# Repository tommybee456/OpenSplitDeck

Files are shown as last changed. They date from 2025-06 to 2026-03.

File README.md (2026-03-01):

# OpenSplitDeck (v0.3)

A custom modular wireless controller inspired by the Steam Deck and Steam Controller. Features trackpads, detachable halves, and full HID support. Built from scratch using nRF52840 microcontrollers and the Enhanced ShockBurst protocol. [Video](https://youtu.be/ycMgIToLav8?si=cVztny4IiIS_V4oI) 

Join the [Discord!](https://discord.gg/ZtV34Hwx7y)

> **Note**  
> This project is in an early development stage — v0.3. Expect breaking changes, bugs, and frequent updates.

---

## 🚀 Project Goals

- 🎮 Emulate a Steam Deck-like controller with modular, wireless halves
- 🖱️ Support mouse, keyboard, and gamepad HID modes
- 🧲 Custom-built trackpads using the Azoteq IQS7211E sensor
- 🔋 Magnetic pogo-pin charging and attachment system
- 🛠️ Fully open-source hardware and firmware

---

## 😎 Current Status

- 🎮 Emulates a DS4 Controller - This lets us use steam input for the trackpads. Ideally I want it to show up as a steamdeck controller but that is seeming like a much harder task than I thought.
- 🖱️ Support mouse, keyboard, and gamepad HID modes. - Kinda. Mouse and keyboard are properly setup in the HID desccriptors, I just have not implpemented them yet.
- 🧲 Custom-built trackpads using the Azoteq IQS7211E sensor - Yes.
- 🔋 Magnetic pogo-pin charging and attachment system. - Yes but they only support charging. I would like to find a way to make the 2 halves of the controller communicate with each other.
- 🛠️ Fully open-source hardware and firmware - 😎

Controller is still definetly in the early phases. However it does function and work as expected. There is still a lot to improve, optimize and other features to add. Stay tuned for the progression of this project and feel free to build one yourself! Let me know if my instructions are bad.

---

## ✅ v0.3 Development Checklist

### Hardware
- [x] Left and right controller halves (nRF52840)
- [x] USB dongle (nRF52840)
- [x] Custom trackpad PCBs (IQS7211E)
- [ ] 3D printable version of the Shell
- [x] Controller PCBs(left + right)
- [ ] Joystick PCBs(to drive down cost)
- [ ] gp2040ce + nrf dongle

### Firmware
- [x] ESB-based wireless communication
- [x] Mouse + Gamepad + Keyboard HID reports
- [x] Input parsing for trackpads and buttons
- [x] Haptics
- [X] Rumble support (Could still be improved)
- [x] Gyro Support
- [x] Calibration routines + save to internal memory
- [ ] Configurable modes (gesture/tap/mouse/gamepad)
- [x] Steam Input compatibility or XInput compatibility(This is now done through DS4)
- [ ] Capacitive Joystick

### 3d Modeling
- [ ] 3d Printable Case(Started, its in the STEP file)
- [ ] 3d Printable Shoulder Button Structure(Experimental Version in STEP file)
- [ ] 3d Printable Trigger Insert
- [ ] Trigger Locks

### Other
- [ ] Improve documentation and diagrams
- [x] Add Screens
- [ ] Design a UI or config utility(either software or adding screens)
- [X] Firmware migration to Zephyr
- [X] Optimize latency and packet loss handling (could still be better)
- [ ] Reduces costs

---

## 📷 Media

[Valve Took Too Long… So I Built the Steam Controller 2](https://youtu.be/ycMgIToLav8?si=yKXbfcrKJxGGkxHx)

[Valve Announced a New Steam Controller… and I Upgraded Mine](https://youtu.be/R8YwpwIV1gQ?si=VNfhFrsPYMe3HJeA)

[LTT Video](https://youtu.be/eNb55ZwnCRc?si=DEBvHWtwEqF-e4JU)

---

## 🛠️ Build Instructions
- Schematic and board files:

  [LeftPCB](https://oshwlab.com/fbrains69/opensteamdeck-buttonpcb)

  [RightPCB](https://oshwlab.com/fbrains69/opensteamdeck-rightpcb)

  [Trackpad](https://oshwlab.com/fbrains69/steamdeck-controller-trackpad-v1-2)
  
- BOM and Tools:

  [Current BOM - Living Sheet (Im Trying to find the best way to source everything still)](https://docs.google.com/spreadsheets/d/1LNsZTH84R0wy0S3vBu-m3nQxl8zSZT1IippI82DKSO4/edit?usp=sharing)

- Build Guide:

  [Video Build Guide](https://youtu.be/64-y5n9kIJc)

  [Written Build Guide](https://github.com/tommybee456/OpenSplitDeck/blob/main/Docs/OpenSplitDeck_Build_Guide.pdf)

---

## 🤝 Contributing

Contributions are welcome! Feel free to fork the repo, open issues, or submit pull requests.

If you're not sure where to start, check out the [Checklist](#-v03-development-checklist) for open tasks.

Special Thanks to:
- TheTitaniumTitan for Suggesting S-Input and providing working example code
- RogueRen for helping make some PCB ordering documentation
- Kuekenzange for making a charging dock 3d Model

---

## 📄 License

MIT License — see `LICENSE` file for details.

---

## 💬 Contact

For questions or suggestions, reach out via GitHub Issues or [YouTube](https://www.youtube.com/@TommyBee456).

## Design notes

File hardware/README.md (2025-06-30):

## ZIF connector pinouts:

> **Note**  
> Please, please, please, double check this with a multimeter before providing power. They should be correct but I dont want you to fry anything.

### OLED Joysitck
Pins Left to right:

|1.|2.|3.|4.|5.|6.|7.|8.|9.|10.|
|-|-|-|-|-|-|-|-|-|-|
|?|GND|?|GND|Key|X|3.3V|Shoulder|Y|3.3V|

### LCD Joystick
Pins Left to right:
|1.|2.|3.|4.|5.|6.|7.|8.|9.|10|
|-|-|-|-|-|-|-|-|-|-|
|?|GND|?|GND|Key|X|3.3V|Shoulder|Y|3.3V|

## Buttons Pinout: (gotta redo this one)
|1.|2.|3.|4.|5.|6.|7.|8.|9.|10|
|-|-|-|-|-|-|-|-|-|-|
|GND|Start|GND|-|GND|-|GND|-|GND|-|

## Dpad Pinout:

|1.|2.|3.|4.|5.|6.|7.|8.|9.|10|
|-|-|-|-|-|-|-|-|-|-|
|GND|Select|GND|Down|GND|Left|GND|Right|GND|Up|

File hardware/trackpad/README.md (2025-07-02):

Note: I've identified a small improvement that can be made to these PCBs, so I'll post V1.2 soon. It will require re-tuning, so the firmware header file for the trackpads will change. I'll make sure to be note the different versions of the file.

Link to project: [here](https://oshwlab.com/fbrains69/steamdeck-controller-trackpad)

Link to easyeda direct: [here](https://pro.easyeda.com/editor#id=08c47b7f10cb451ca88fb6954f92a96d)

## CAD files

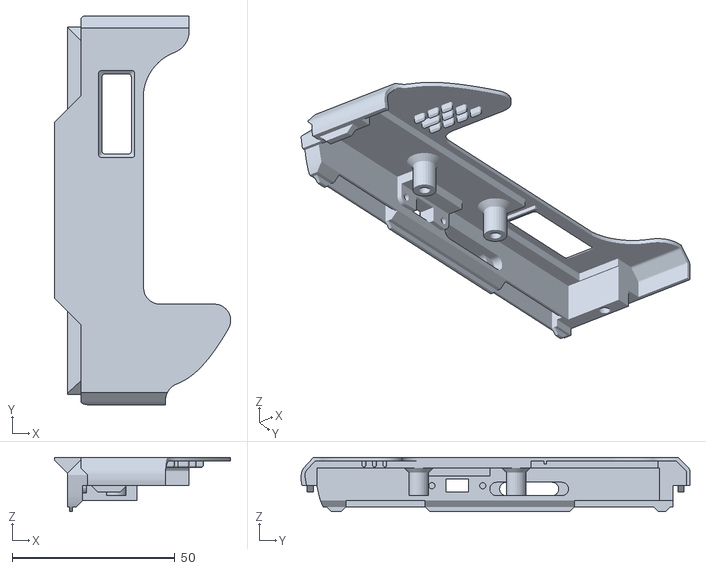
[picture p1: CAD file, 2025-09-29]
CAD/Connector Halves/Right Controller v3 Top.stl
54.2 x 119.4 x 16.7

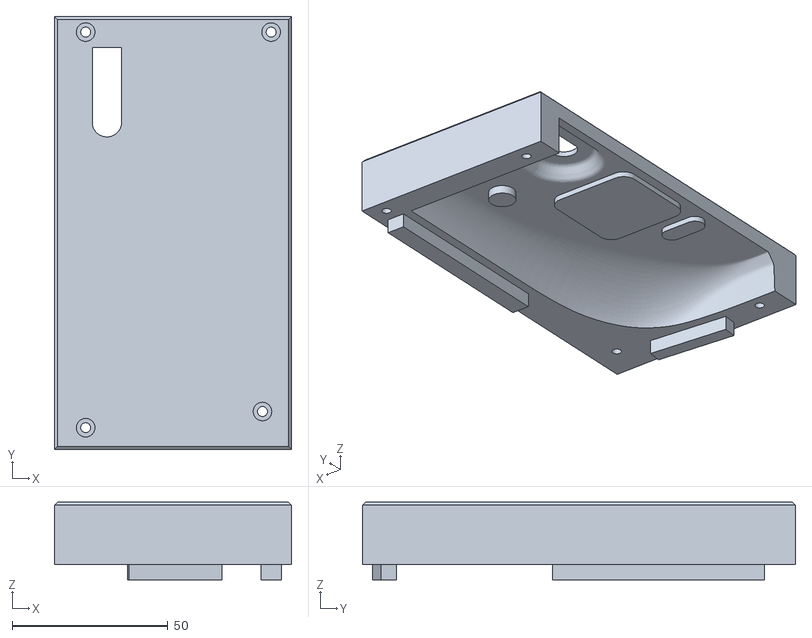
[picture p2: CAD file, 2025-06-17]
CAD/cutting jig/Top Right.stl
76.0 x 138.8 x 25.0

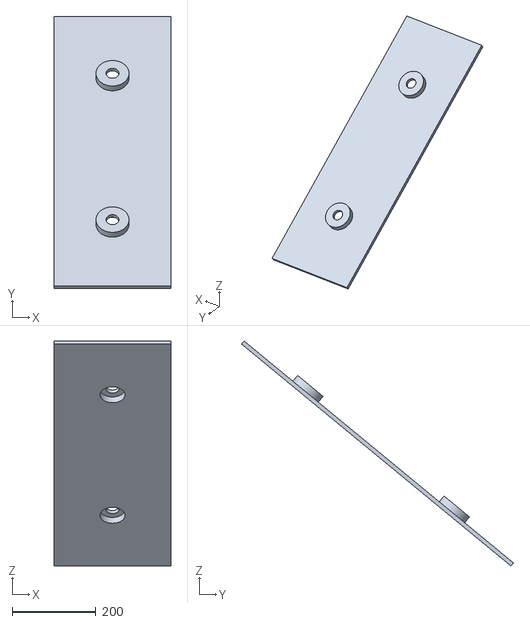
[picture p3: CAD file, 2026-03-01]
CAD/Dock+Dongle/HollowBottomLid.stl
279.4 x 649.8 x 537.5

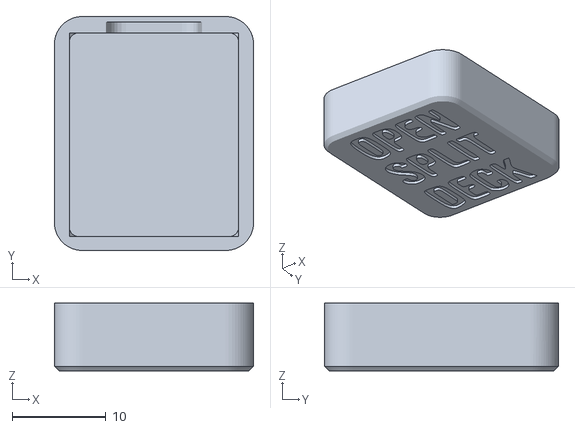
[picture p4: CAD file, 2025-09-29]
CAD/Dongle Case/Bottom Dongle Case.stl
21.3 x 25.0 x 7.25

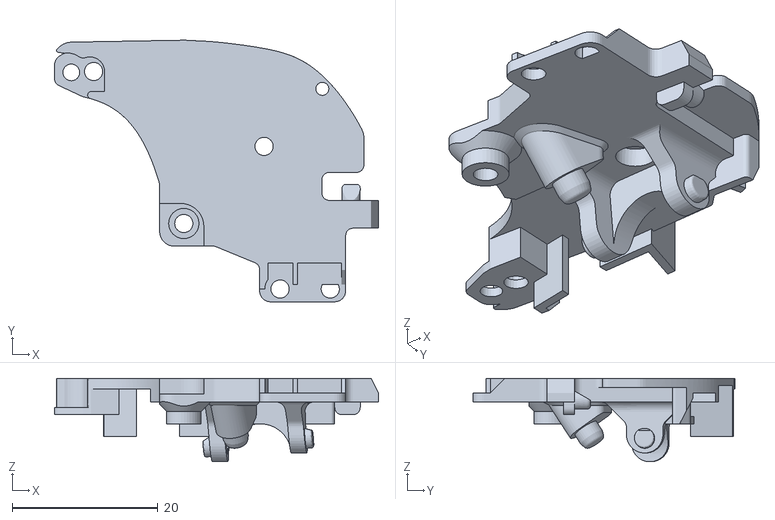
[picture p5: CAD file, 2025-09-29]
CAD/TODO 3D Printable Case/Right Bumper experimental.stl
44.4 x 35.9 x 11.4

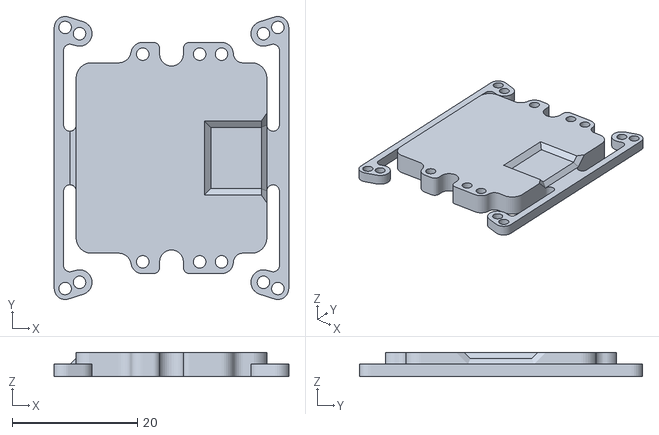
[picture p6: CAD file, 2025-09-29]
CAD/Trackpad Spring/Trackpad Spring.stl
37.5 x 45.2 x 3.90

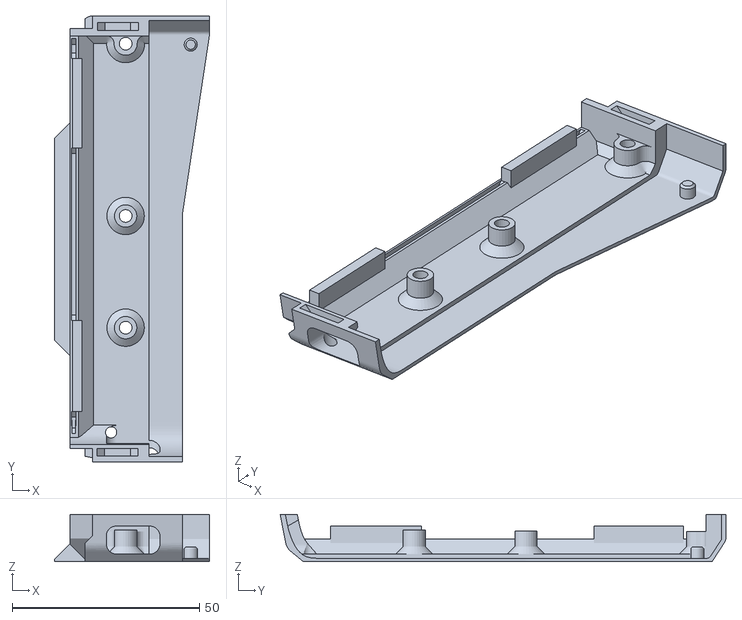
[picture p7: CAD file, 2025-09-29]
CAD/Connector Halves/Right Controller v3 Bottom.stl
41.4 x 119.1 x 12.6

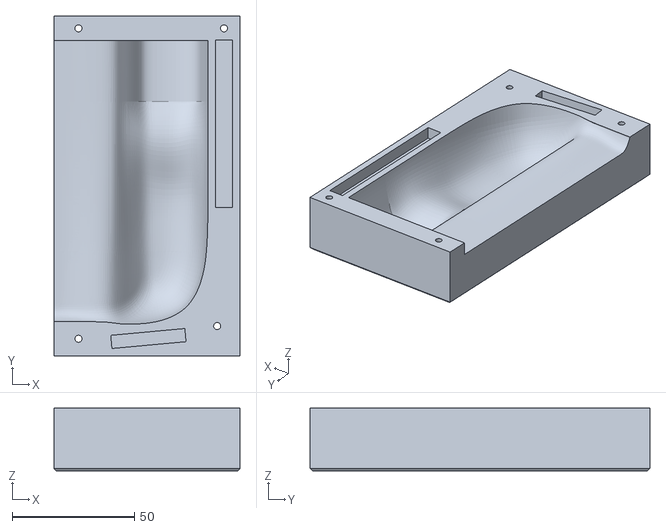
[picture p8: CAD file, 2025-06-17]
CAD/cutting jig/Bottom Right.stl
76.0 x 138.8 x 25.7

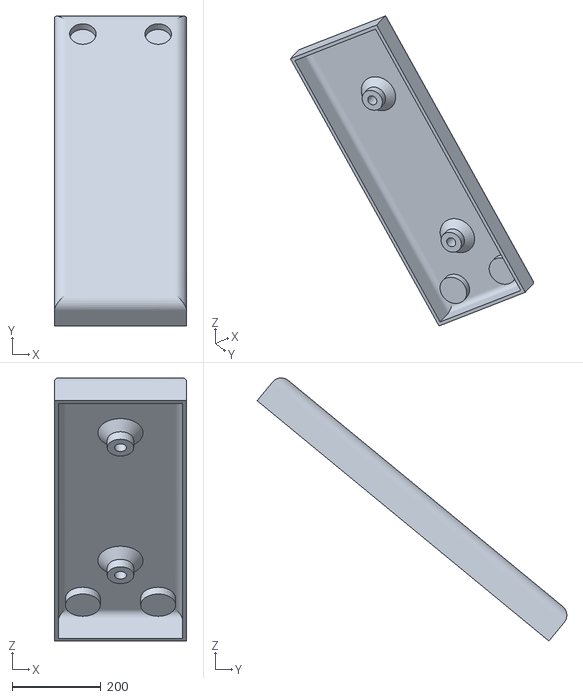
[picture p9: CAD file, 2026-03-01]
CAD/Dock+Dongle/HollowBottom.stl
298.4 x 698.9 x 593.5

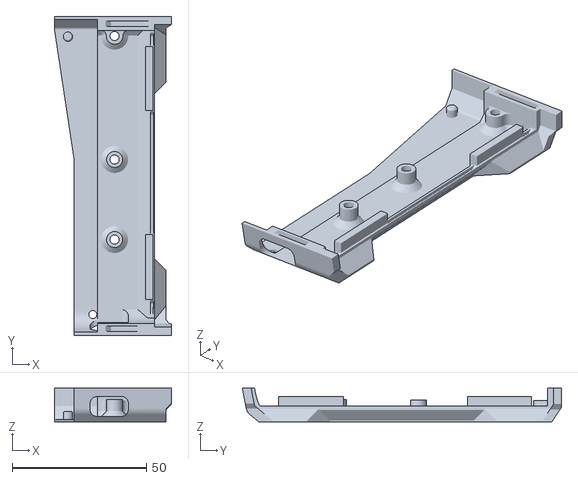
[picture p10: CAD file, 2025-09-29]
CAD/Connector Halves/Left Controller v3 Bottom.stl
43.6 x 119.1 x 12.6

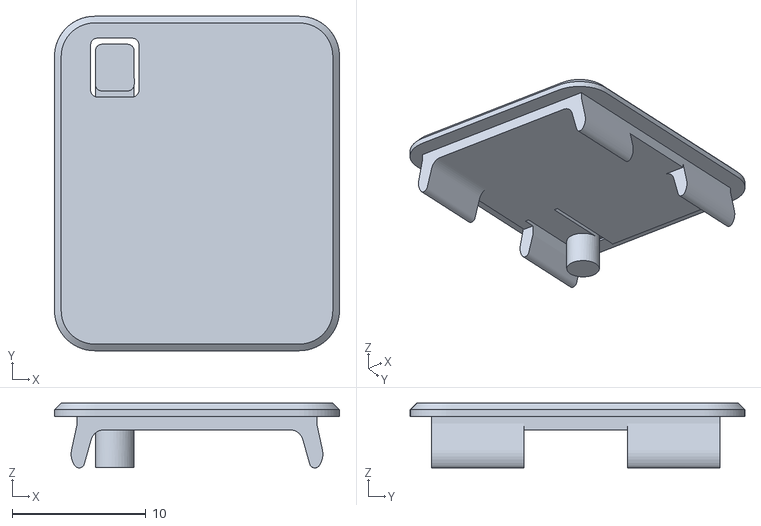
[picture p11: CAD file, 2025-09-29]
CAD/Dongle Case/Top Dongle Case.stl
21.3 x 25.0 x 4.85

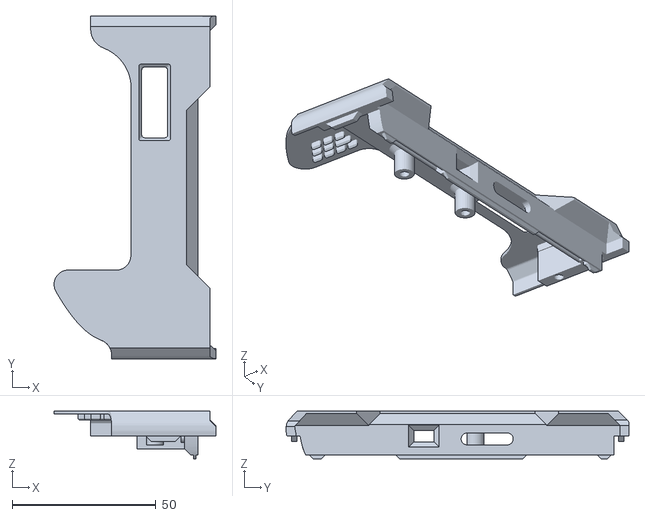
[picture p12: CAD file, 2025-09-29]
CAD/Connector Halves/Left Controller v3 Top.stl
56.4 x 119.4 x 16.7

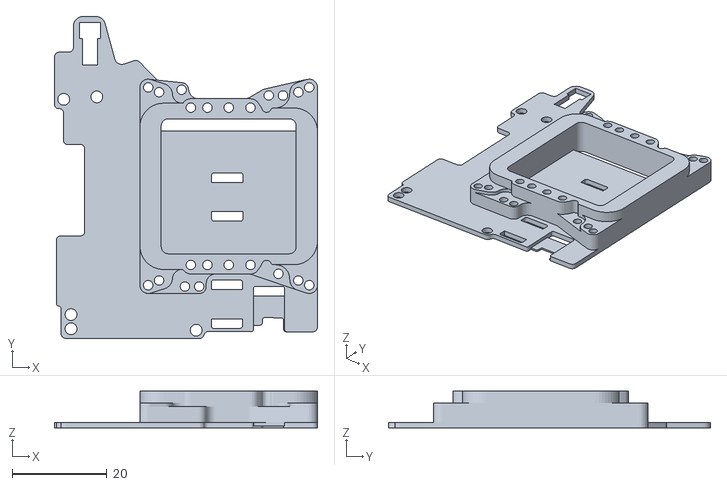
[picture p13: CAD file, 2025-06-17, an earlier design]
CAD/Old/sudoPCB/Fake PCB Oled Trackpad Left.stl
55.5 x 68.0 x 7.80

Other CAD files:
CAD/Dongle Case/Bottom Dongle Case 2.stl
CAD/cutting jig/Bottom Left.stl
CAD/cutting jig/Top Left.stl
CAD/Old/sudoPCB/Fake PCB LCD Trackpad Right.stl
CAD/Old/sudoPCB/Fake PCB Oled Trackpad Right.stl
CAD/Old/sudoPCB/Fake PCB LCD Trackpad Left.stl

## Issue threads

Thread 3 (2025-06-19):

Idea for getting Steam to recognize Trackpads and Gyro in Steam Input

aarron-lee, 2025-06-19:
If you can get the controller to pretend to be a Dualsense Edge controller, you can theoretically get nearly all functionality to work with Steam Input.

This is because the Dualsense Edge has:

- gyro
- dual trackpads
  - technically 3 trackpads, Steam Input recognizes the dualsense trackpad as three trackpads, left + right + center
- 4 extra remappable "back" buttons

This is already being done in the Linux community via software like [hhd](https://github.com/hhd-dev/hhd) and [InputPlumber](https://github.com/ShadowBlip/InputPlumber/) for adding controller support for non-Deck handhelds.

e.g. on the Legion Go + Linux, you can get RGB + gyro + extra back button support in Steam Input working via emulating a Dualsense Edge controller.

edit: theoretically, you can get this controller working today in Steam Input via Linux + InputPlumber + a custom capability map. InputPlumber takes inputs from multiple devices, and combines them into an emulated output device. You can actually map it to an actual emulated Deck controller if you configure it correctly.

tommybee456, 2025-06-30:
oh interesting, so a software solution? That definetly seems doable since it is already showing as mutiple devices. I will look more into this!

Closed 2025-06-30.

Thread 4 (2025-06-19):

Suggestion: trigger stops.

this-is-just-con-tribute, 2025-06-19:
That would help make this the ultimate controller. That is all.

tommybee456, 2025-06-30:
This would require some mechanical design changes to the actual controller half. I already plan on making a full 3d printable case, maybe I make a separate checklist for 3d modeling goals?

tommybee456, 2025-09-29:
Just bumping this because I still like the idea, will definitely require some creative mechanical engineering.

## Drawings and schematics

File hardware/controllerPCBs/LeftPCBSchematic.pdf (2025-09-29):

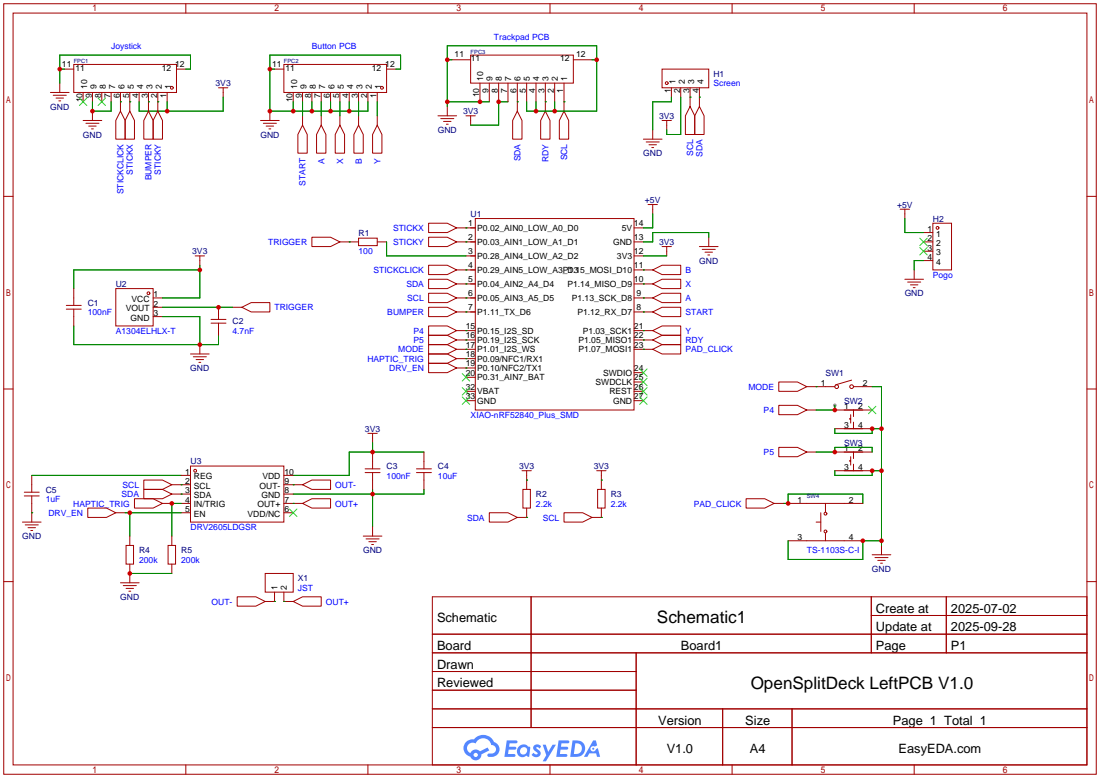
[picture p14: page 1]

Schematic | Schematic1 | Create at | 2025-07-02

Update at | 2025-09-28

Board | Board1 | Page | P1
Drawn | | OpenSplitDeck LeftPCB V1.0
Reviewed

Version | Size | Page 1 Total 1
V1.0 | A4 | EasyEDA.com

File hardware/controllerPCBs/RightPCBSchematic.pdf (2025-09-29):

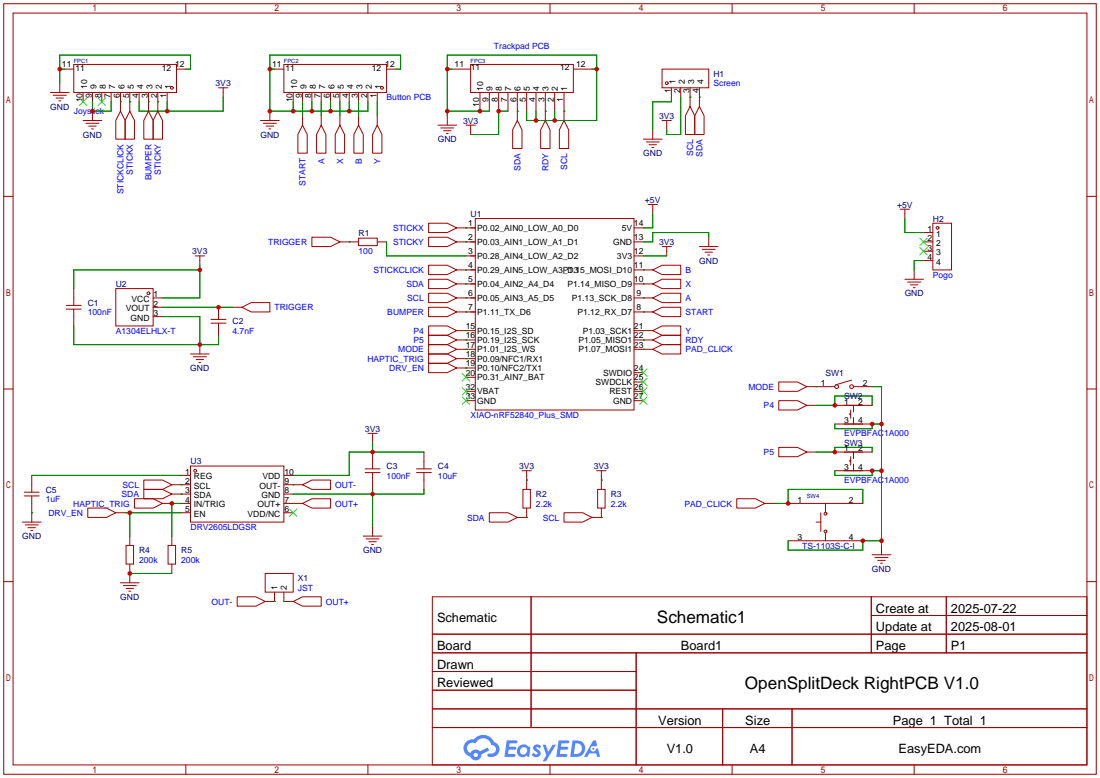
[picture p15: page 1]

Schematic | Schematic1 | Create at | 2025-07-22

Update at | 2025-08-01

Board | Board1 | Page | P1
Drawn | | OpenSplitDeck RightPCB V1.0
Reviewed

Version | Size | Page 1 Total 1
V1.0 | A4 | EasyEDA.com

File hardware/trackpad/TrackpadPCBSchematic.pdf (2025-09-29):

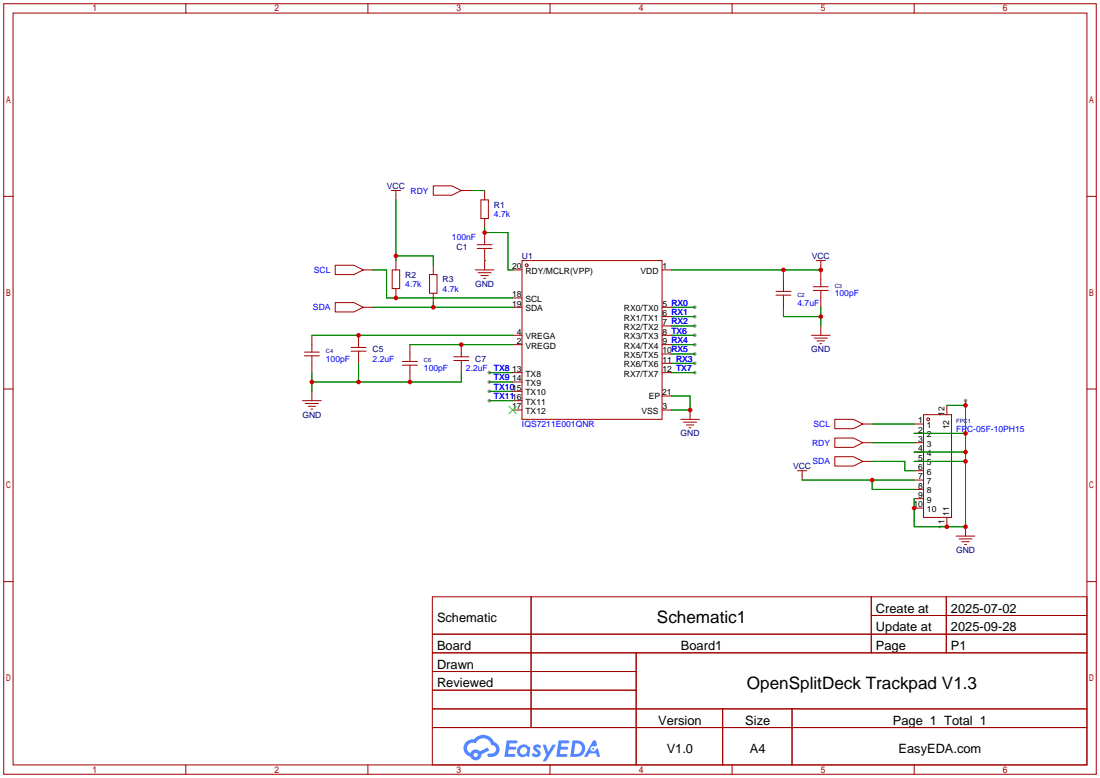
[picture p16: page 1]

Schematic | Schematic1 | Create at | 2025-07-02

Update at | 2025-09-28

Board | Board1 | Page | P1
Drawn | | OpenSplitDeck Trackpad V1.3
Reviewed

Version | Size | Page 1 Total 1
V1.0 | A4 | EasyEDA.com

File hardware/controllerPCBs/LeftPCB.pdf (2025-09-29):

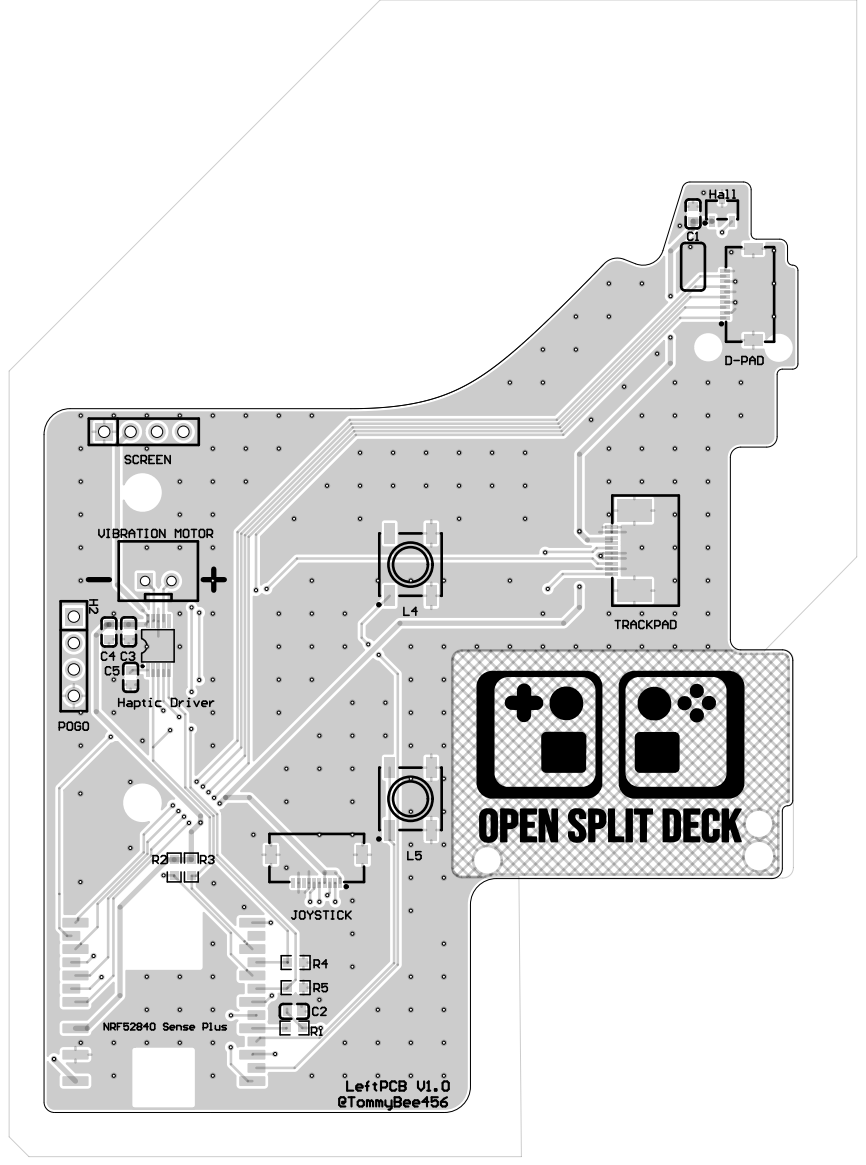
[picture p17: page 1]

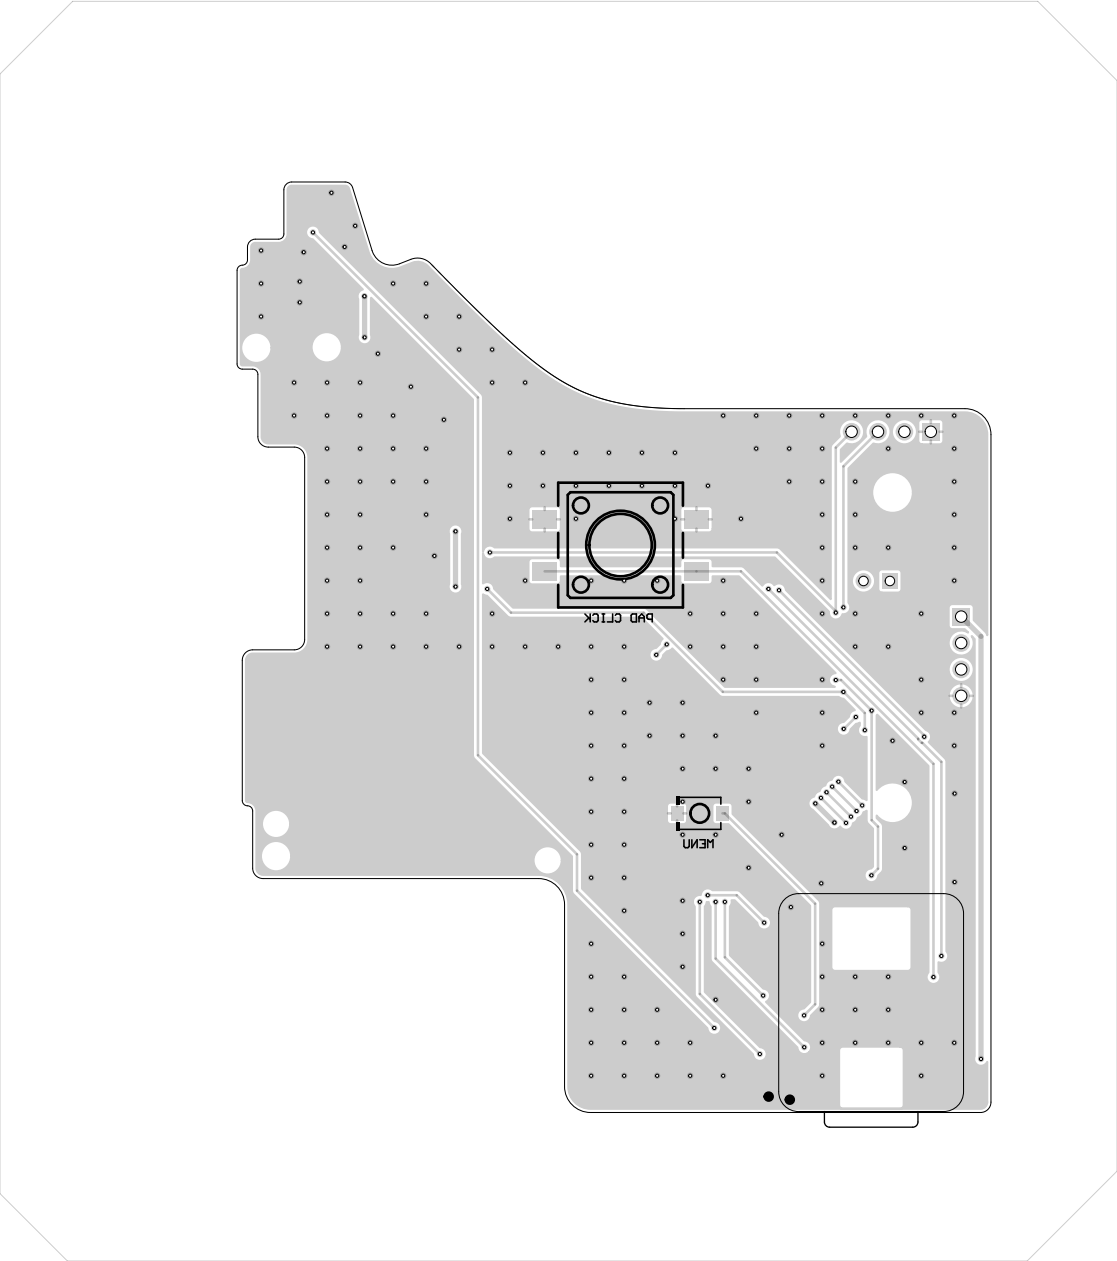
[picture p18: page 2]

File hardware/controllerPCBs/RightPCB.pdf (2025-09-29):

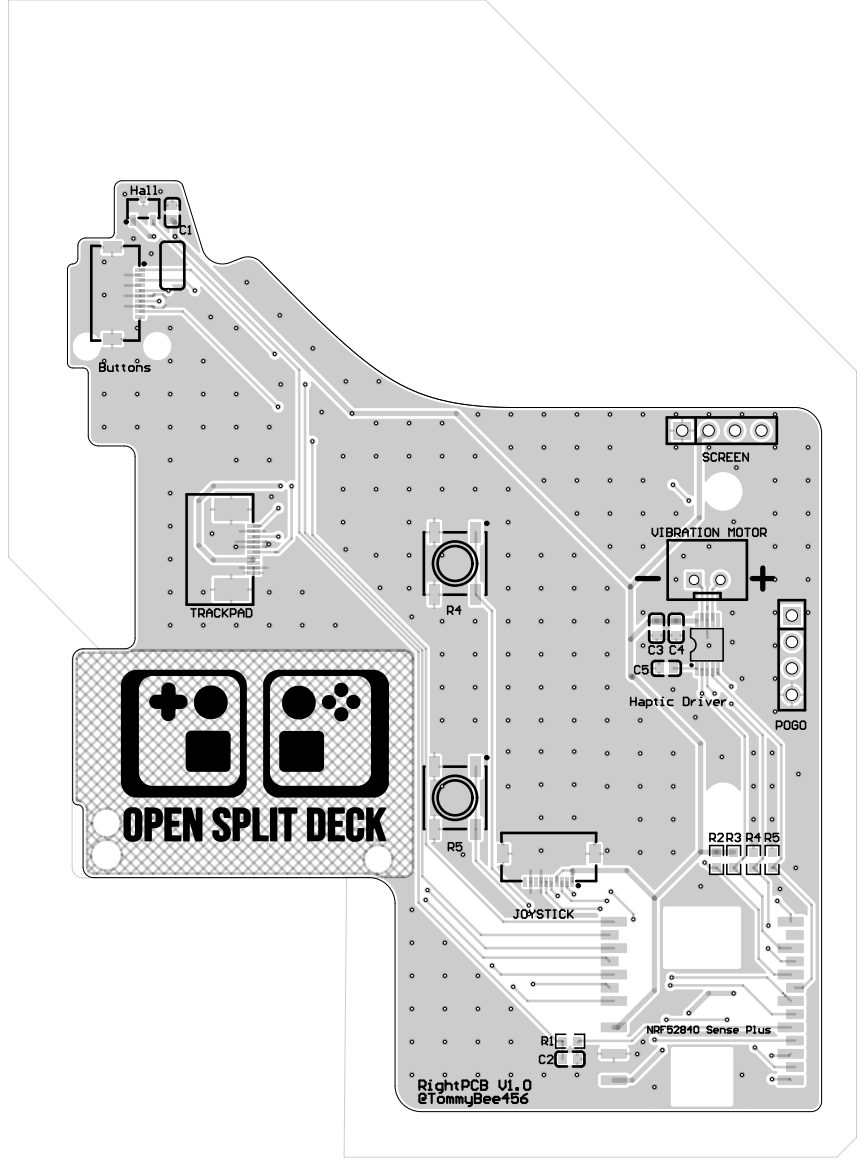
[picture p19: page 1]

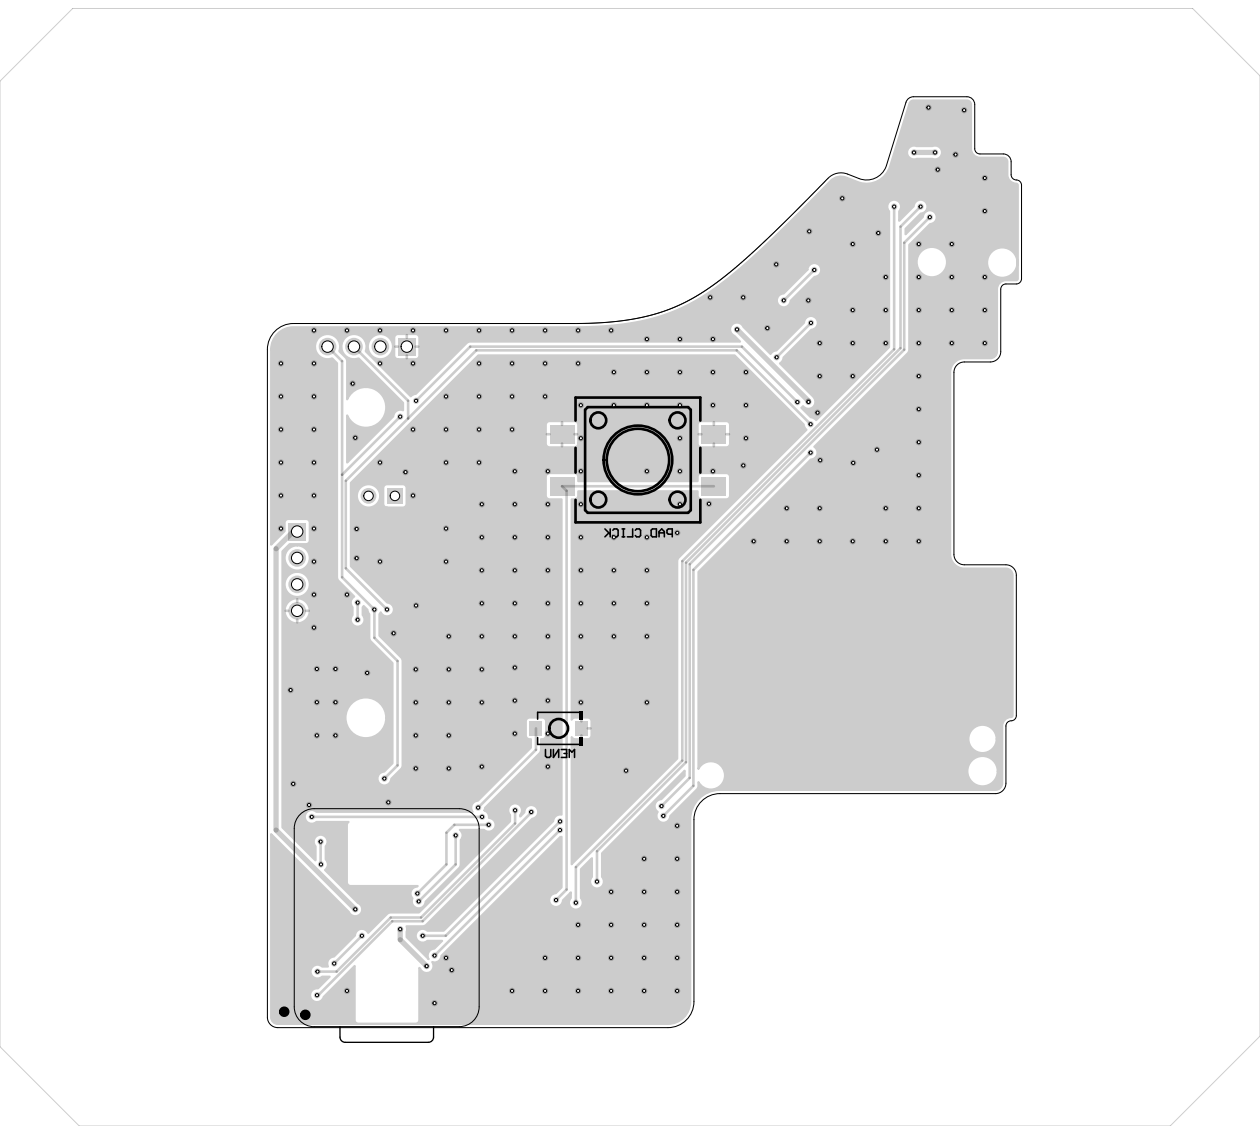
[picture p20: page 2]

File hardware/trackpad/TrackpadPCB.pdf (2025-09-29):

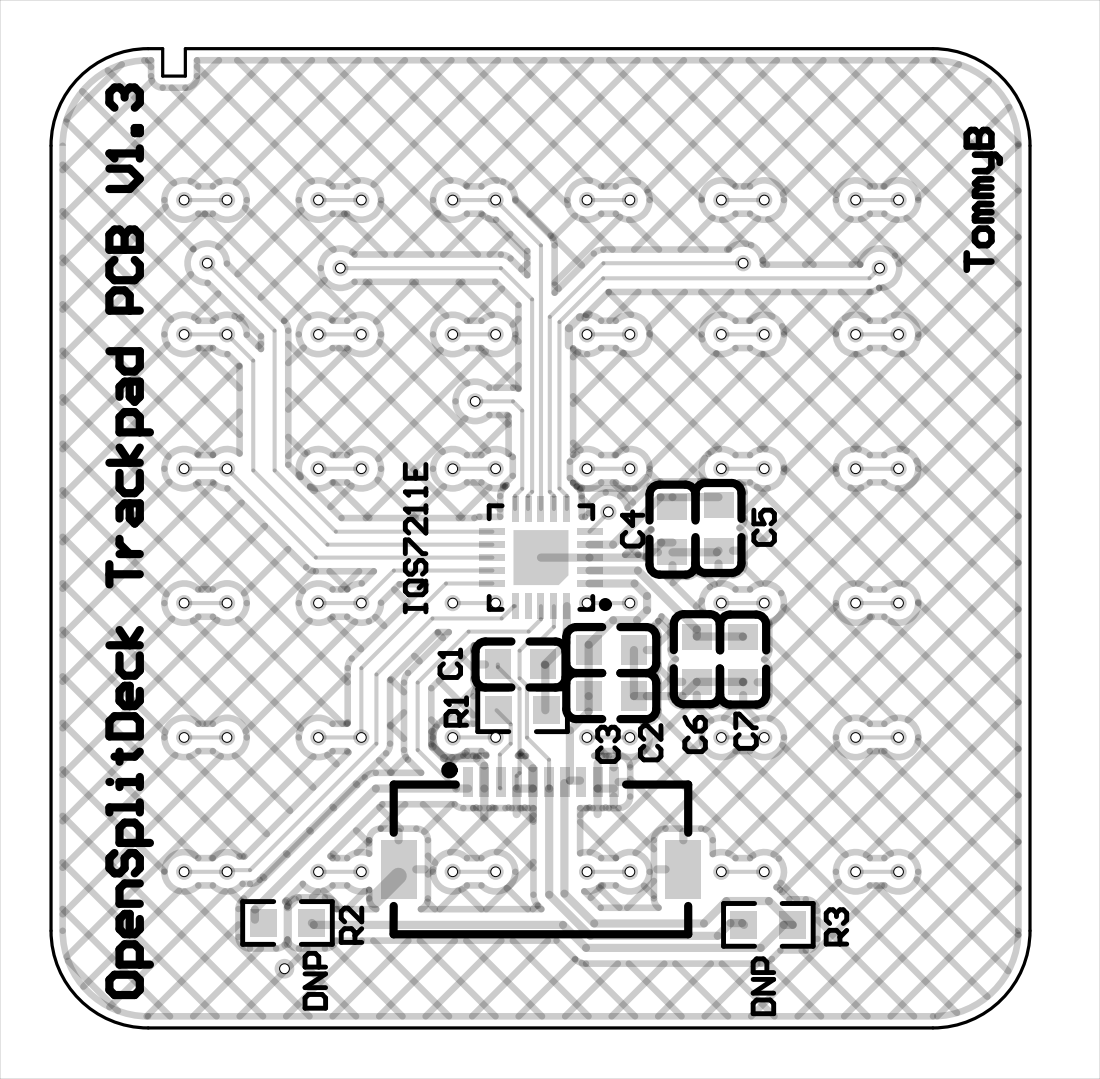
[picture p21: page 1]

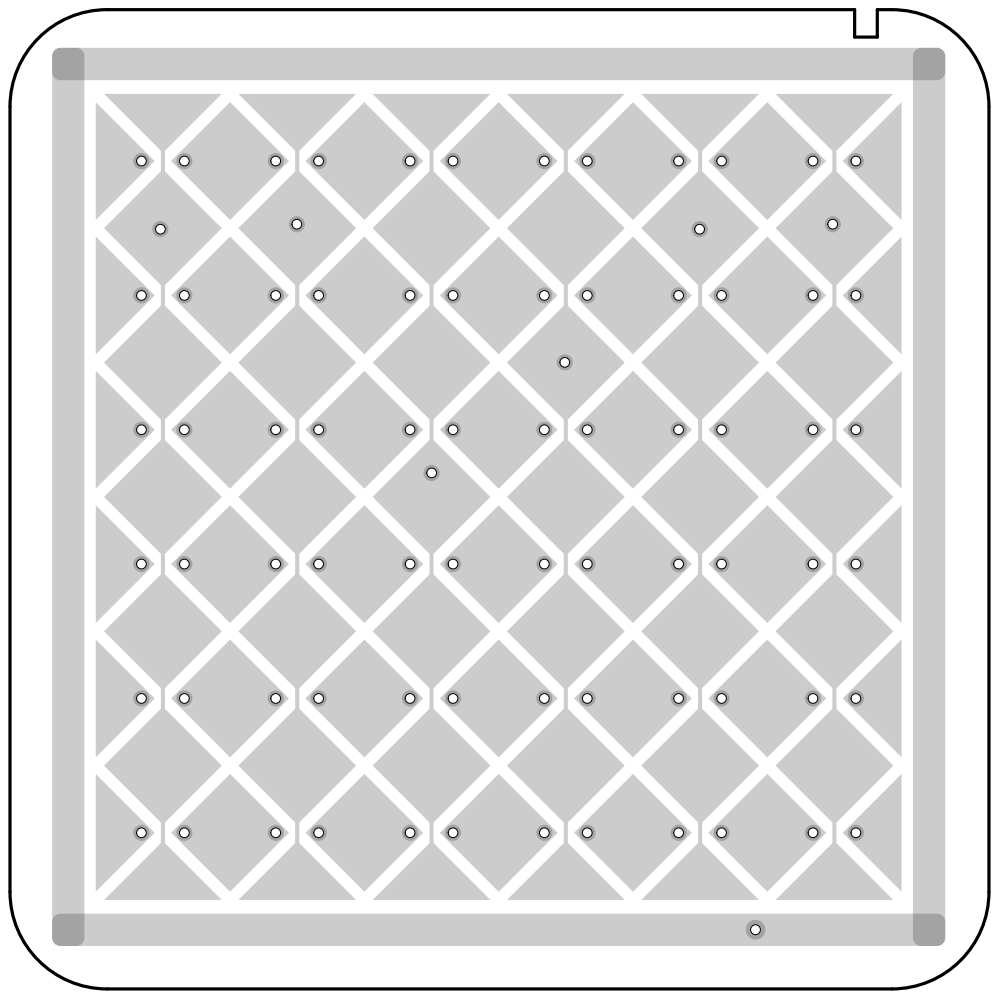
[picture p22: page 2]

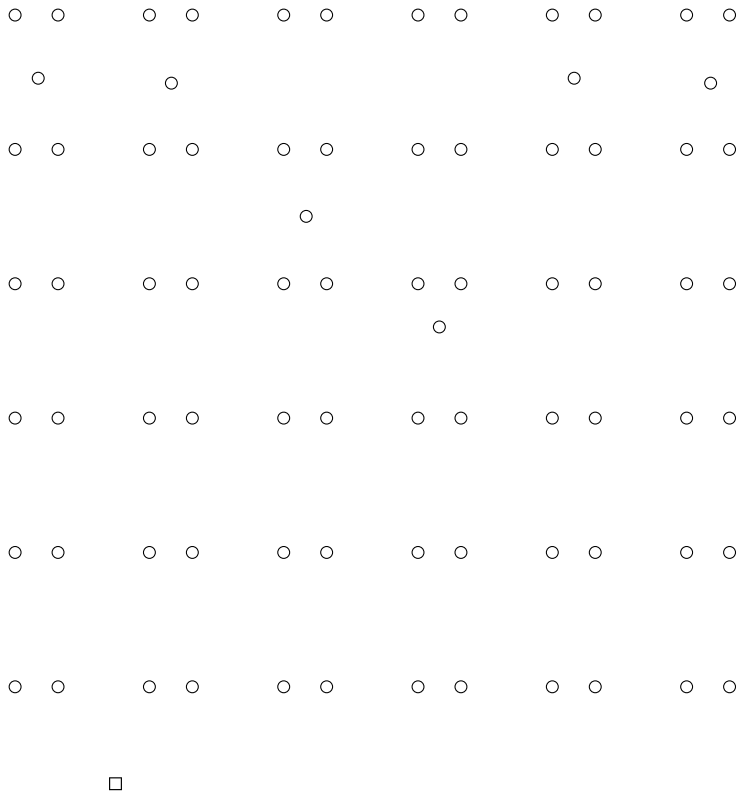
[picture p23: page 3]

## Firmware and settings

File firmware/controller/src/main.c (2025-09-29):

/*
 * Dual Controller System - Zephyr ESB Implementation
 *
 * This code runs on a Seeed Xiao BLE nRF52840 Sense Plus
 * It can be configured as LEFT or RIGHT controller half
 * Each half has a unique ID and only responds to its specific ping
 *
 * Configuration: Set CONTROLLER_ID below
 * - 0 = RIGHT controller (responds to ping value 0)
 * - 1 = LEFT controller (responds to ping value 1)
 */

// ========================
// CONTROLLER CONFIGURATION
// ========================
#define CONTROLLER_ID 1 // Change to 0 for RIGHT controller, 1 for LEFT controller

// FREEZE DEBUGGING - Temporarily disable components to isolate freezing source
#define FREEZE_DEBUG_DISABLE_ADC 0 // Set to 1 to disable ADC reads
#define FREEZE_DEBUG_DISABLE_IMU 0 // Set to 1 to disable IMU reads

#include <zephyr/kernel.h>
#include <zephyr/device.h>
#include <zephyr/drivers/gpio.h>
#include <zephyr/drivers/i2c.h>
#include <zephyr/pm/device.h>
#include <zephyr/drivers/sensor.h>
#include <zephyr/drivers/adc.h>
#include <zephyr/drivers/clock_control.h>
#include <zephyr/drivers/clock_control/nrf_clock_control.h>
#include <hal/nrf_saadc.h>
#include <nrfx_saadc.h>
#include <zephyr/pm/pm.h>
#include <zephyr/pm/state.h>
#include <zephyr/logging/log.h>
#if defined(CONFIG_ADC_NRFX_SAADC)
#include <nrfx_saadc.h>
#endif
#include <math.h>
#include <esb.h>
#include "IQS7211E.h"
#include "controller_storage.h"
#include "drv2605.h"
#include "display.h"
#include "haptic_driver.h"
#include "imu_driver.h"
#include "button_driver.h"
#include "analog_driver.h"
#include "esb_comm_driver.h"
#include "power_mgmt_driver.h"
#include "IQS7211E_init.h"
// #include "trackpad_driver.h"

LOG_MODULE_REGISTER(controller, LOG_LEVEL_INF);

// LED for status indication
static const struct gpio_dt_spec led0 = GPIO_DT_SPEC_GET(DT_ALIAS(led0), gpios);

// Display State Varibles
static display_screen_type_t current_display_screen = DISPLAY_SCREEN_STATUS;
static display_analog_data_t display_analog_data = {0};
// REMOVED display_mutex - was causing priority inversion and 100-160ms thread delays
// Main thread (200Hz) calling display_set_screen competed with display thread (20Hz)

// I2C bus protection - REMOVED due to causing thread delays
// static K_MUTEX_DEFINE(i2c1_mutex);

// Thread health monitoring
static uint32_t trackpad_thread_heartbeat = 0;
static uint32_t display_thread_heartbeat = 0;

// Controller button GPIO definitions (used by button driver)
static const struct gpio_dt_spec stick_click = {
    .port = DEVICE_DT_GET(DT_NODELABEL(gpio0)),
    .pin = 29,
    .dt_flags = GPIO_ACTIVE_LOW};

static const struct gpio_dt_spec bumper = {
    .port = DEVICE_DT_GET(DT_NODELABEL(gpio1)),
    .pin = 11,
    .dt_flags = GPIO_ACTIVE_LOW};

static const struct gpio_dt_spec start = {
    .port = DEVICE_DT_GET(DT_NODELABEL(gpio1)),
    .pin = 12,
    .dt_flags = GPIO_ACTIVE_LOW};

static const struct gpio_dt_spec button_p4 = {
    .port = DEVICE_DT_GET(DT_NODELABEL(gpio0)),
    .pin = 15,
    .dt_flags = GPIO_ACTIVE_LOW};

static const struct gpio_dt_spec button_p5 = {
    .port = DEVICE_DT_GET(DT_NODELABEL(gpio0)),
    .pin = 19,
    .dt_flags = GPIO_ACTIVE_LOW};

static const struct gpio_dt_spec mode_button = {
    .port = DEVICE_DT_GET(DT_NODELABEL(gpio1)),
    .pin = 1,
    .dt_flags = GPIO_ACTIVE_LOW};

static const struct gpio_dt_spec dpad_down = {
    .port = DEVICE_DT_GET(DT_NODELABEL(gpio1)),
    .pin = 13,
    .dt_flags = GPIO_ACTIVE_LOW};

static const struct gpio_dt_spec dpad_left = {
    .port = DEVICE_DT_GET(DT_NODELABEL(gpio1)),
    .pin = 14,
    .dt_flags = GPIO_ACTIVE_LOW};

static const struct gpio_dt_spec dpad_right = {
    .port = DEVICE_DT_GET(DT_NODELABEL(gpio1)),
    .pin = 15,
    .dt_flags = GPIO_ACTIVE_LOW};

static const struct gpio_dt_spec dpad_up = {
    .port = DEVICE_DT_GET(DT_NODELABEL(gpio1)),
    .pin = 3,
    .dt_flags = GPIO_ACTIVE_LOW};

static const struct gpio_dt_spec pad_click = {
    .port = DEVICE_DT_GET(DT_NODELABEL(gpio1)),
    .pin = 7,
    .dt_flags = GPIO_ACTIVE_LOW};

// DRV2605 Haptic motor control pins (NFC pins - requires NFC disabled)
static const struct gpio_dt_spec haptic_trigger = {
    .port = DEVICE_DT_GET(DT_NODELABEL(gpio0)),
    .pin = 9, // P0.09 (NFC1) - External trigger pin
    .dt_flags = GPIO_ACTIVE_HIGH};

static const struct gpio_dt_spec haptic_enable_pin = {
    .port = DEVICE_DT_GET(DT_NODELABEL(gpio0)),
    .pin = 10, // P0.10 (NFC2) - Enable pin
    .dt_flags = GPIO_ACTIVE_HIGH};

// Battery voltage divider enable pin (XIAO nRF52840)
static const struct gpio_dt_spec vbat_enable = {
    .port = DEVICE_DT_GET(DT_NODELABEL(gpio0)),
    .pin = 14,                    // P0.14 - Battery voltage divider enable (LOW=enabled, HIGH=disabled)
    .dt_flags = GPIO_ACTIVE_LOW}; // Active low means setting to 0 enables the divider

// Trackpad RDY pin for interrupt-based reading
static const struct gpio_dt_spec trackpad_rdy = {
    .port = DEVICE_DT_GET(DT_NODELABEL(gpio1)),
    .pin = 5, // P1.05 - RDY pin from trackpad
    .dt_flags = GPIO_ACTIVE_LOW | GPIO_INT_EDGE_FALLING};

// Removed unused trackpad_ready GPIO spec

// I2C for peripherals
static const struct device *i2c_dev;

// IMU sensor - Now using imu_driver library

// ADC for analog inputs - Now using analog_driver library
static const struct device *adc_dev;

// Forward declarations for power management functions
void shutdown_all_peripherals(void);
void wakeup_all_peripherals(void);
void power_factory_reset_handler(void);

// Global flag to track if we need safe shutdown
// Sleep mode state

// Storage for configuration data
static controller_calibration_t controller_calibration;
static controller_bindings_t controller_bindings;
static controller_preferences_t controller_preferences;

// ESB payload structures - now using ESB communication driver
// Controller state
static esb_controller_data_t controller_data = {0};

// Function declarations
void buttons_init(void);                      // Initialize button driver
void adc_init(void);                          // Initialize analog driver
void esb_comm_init(void);                     // Initialize ESB communication driver
void read_button_inputs(void);                // Read buttons using driver
void read_analog_inputs(void);                // Read analog using driver
void print_analog_values(void);               // Debug: print all analog values
void calibrate_analog_inputs(void);           // Calibrate analog using driver
void read_trackpad_inputs(void);              // Read trackpad using driver
void read_imu_inputs(void);                   // Read IMU using driver
esb_comm_status_t send_controller_data(void); // Send data using ESB driver
void power_mgmt_init(void);                   // Initialize power management driver
void ui_init(void);                           // UI placeholder functions
void ui_create_main_screen(void);
void ui_create_menu_screen(void);
void ui_create_calibration_screen(void);
void ui_update_data(void);
void ui_handle_input(void);

// Initialize ESB communication using ESB driver library
void esb_comm_init(void)
{
        LOG_INF("Initializing ESB communication using driver library...");

        // Configure ESB communication
        // Configure timing with controller-specific offset to prevent collisions
        uint32_t base_interval = 5;   // 5ms base for RIGHT controller
        uint32_t retry_interval = 10; // 10ms retry for RIGHT controller

        // LEFT controller gets +2ms offset to stagger transmissions
        if (CONTROLLER_ID == 1)
        {                            // LEFT controller
                base_interval += 2;  // 7ms instead of 5ms
                retry_interval += 2; // 12ms instead of 10ms
        }

        esb_comm_config_t esb_config = {
            .controller_id = CONTROLLER_ID,
            .base_tx_interval_ms = base_interval,
            .retry_interval_ms = retry_interval,
            .rf_channel = 1,    // RF channel 1
            .status_led = &led0 // Use LED0 for status indication
        };

        LOG_INF("Controller %d ESB timing: base=%dms, retry=%dms (offset for collision avoidance)",
                CONTROLLER_ID, base_interval, retry_interval);
        LOG_INF("Note: Actual timing controlled by dongle ACK payload when available");

        esb_comm_status_t status = esb_comm_driver_init(&esb_config);
        if (status != ESB_COMM_STATUS_OK)
        {
                LOG_ERR("ESB communication driver initialization failed: %d", status);
                return;
        }

        // Enable ACK payload based timing
        status = esb_comm_enable_ack_timing(true);
        if (status == ESB_COMM_STATUS_OK)
        {
                LOG_INF("ACK payload timing enabled");
        }
        else
        {
                LOG_WRN("Failed to enable ACK payload timing: %d", status);
        }

        LOG_INF("ESB communication driver initialized successfully");
}

// Send controller data using ESB driver library with ACK payload timing
esb_comm_status_t send_controller_data(void)
{
        // Use the ESB communication driver for transmission
        esb_comm_status_t status = esb_comm_send_data(&controller_data);

        // Process ACK payload data if transmission was successful
        if (status == ESB_COMM_STATUS_OK)
        {
                // Check for rumble data from dongle
                uint8_t left_rumble, right_rumble;
                esb_comm_status_t rumble_status = esb_comm_get_rumble_data(&left_rumble, &right_rumble);

                if (rumble_status == ESB_COMM_STATUS_OK && (left_rumble > 0 || right_rumble > 0))
                {
                        // TODO: Implement rumble motor control when hardware is ready
                        static uint32_t last_rumble_log = 0;
                        uint32_t now = k_uptime_get_32();
                        if ((now - last_rumble_log) > 1000)
                        { // Log every 1 second to avoid spam
                                LOG_DBG("Rumble data received - Left: %d/15, Right: %d/15", left_rumble, right_rumble);
                                last_rumble_log = now;
                        }
                }
        }

        // Track radio busy conditions
        static uint32_t busy_count = 0;
        static uint32_t last_busy_log = 0;
        static uint32_t total_send_attempts = 0;

        total_send_attempts++;

        if (status == ESB_COMM_STATUS_BUSY)
        {
                busy_count++;
                uint32_t now = k_uptime_get_32();
                if ((now - last_busy_log) > 5000)
                { // Log every 5 seconds instead of 1
                        LOG_WRN("Radio busy: %u/%u attempts (%.1f%%) - potential overload",
                                busy_count, total_send_attempts,
                                (double)busy_count * 100.0 / total_send_attempts);
                        last_busy_log = now;
                        // Reset counters for next period
                        busy_count = 0;
                        total_send_attempts = 0;
                }
        }
        else if (status != ESB_COMM_STATUS_OK)
        {
                // Log other ESB errors to debug radio failures
                static uint32_t error_count = 0;
                static uint32_t last_error_log = 0;
                error_count++;

                uint32_t now = k_uptime_get_32();
                if ((now - last_error_log) > 2000) // Log every 2 seconds
                {
                        LOG_ERR("ESB transmission error: %d (count: %u/%u)",
                                status, error_count, total_send_attempts);
                        last_error_log = now;
                }
        }

        // Removed verbose ESB transmission logging
        static uint32_t tx_debug_counter = 0;
        if (status == ESB_COMM_STATUS_OK)
        {
                tx_debug_counter++;
                // Removed trackpad transmission debug logs
        }

        return status;
}

// Simulate different controller inputs
void update_controller_data(void)
{
        // Clear previous input state but preserve controller ID in flags
        controller_data.buttons = 0;
        controller_data.flags &= 0x80; // Keep only controller ID (bit 7), clear all other flags
        // controller_data.stickX = 0;
        // controller_data.stickY = 0;
        // controller_data.trigger = 0;
        controller_data.accelX = 0;
        controller_data.accelY = 0;
        controller_data.accelZ = 0;
        controller_data.gyroX = 0;
        controller_data.gyroY = 0;
        controller_data.gyroZ = 0;

        // Read real inputs using new driver libraries with timing diagnostics
        uint32_t start_cycles, end_cycles, duration_us;

        // Measure button reading time
        start_cycles = k_cycle_get_32();
        read_button_inputs(); // Use button driver library
        end_cycles = k_cycle_get_32();
        duration_us = k_cyc_to_us_floor32(end_cycles - start_cycles);
        if (duration_us > 500)
        { // >0.5ms for button reading is slow (lowered threshold)
                LOG_WRN("SLOW BUTTON READ: %dus", duration_us);
        }

        // Measure analog reading time with DETAILED diagnostics + ROUND-ROBIN READING
        // Only read ONE ADC channel per loop to prevent freezing from multi-channel blocking

        start_cycles = k_cycle_get_32();
#if FREEZE_DEBUG_DISABLE_ADC == 0
        // ADC reading handled by dedicated thread - just get the current data
        read_analog_inputs(); // Use existing analog driver function
        // If we didn't read this loop, analog values remain from last read
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
int main(void)
{
        int ret;

        LOG_INF("Zephyr ESB Controller Starting...");

        // Initialize LED
        if (!gpio_is_ready_dt(&led0))
        {
                LOG_ERR("LED device not ready");
                return -ENODEV;
        }
        gpio_pin_configure_dt(&led0, GPIO_OUTPUT_INACTIVE);

        // Initialize battery voltage divider (XIAO nRF52840 safe approach)
        if (!gpio_is_ready_dt(&vbat_enable))
        {
                LOG_ERR("VBAT enable GPIO not ready");
                return -ENODEV;
        }

        // Try different GPIO configuration approaches for P0.14
        LOG_INF("Attempting to configure P0.14 as current sink for voltage divider control...");

        // Method 1: Open-drain output (proper current sink)
        ret = gpio_pin_configure_dt(&vbat_enable, GPIO_OUTPUT_INACTIVE | GPIO_OPEN_DRAIN);
        if (ret != 0)
        {
                LOG_ERR("Failed to configure P0.14 as open-drain: %d", ret);
        }

        ret = gpio_pin_set_dt(&vbat_enable, 0); // Active LOW for current sink
        if (ret != 0)
        {
                LOG_ERR("Failed to set P0.14 to 0: %d", ret);
        }

        // Method 2: If open-drain not supported, try standard output with pull-down
        if (ret != 0)
        {
                ret = gpio_pin_configure_dt(&vbat_enable, GPIO_OUTPUT | GPIO_PULL_DOWN);
                if (ret == 0)
                {
                        ret = gpio_pin_set_dt(&vbat_enable, 0);
                        int pin_state = gpio_pin_get_dt(&vbat_enable);
                        LOG_INF("Method 2 (output+pulldown) result: set_result=%d, pin_state=%d", ret, pin_state);
                }
        }

        // Method 3: Raw GPIO register access for open-drain if needed
        if (ret != 0)
        {
                const struct device *gpio_dev = DEVICE_DT_GET(DT_NODELABEL(gpio0));
                if (device_is_ready(gpio_dev))
                {
                        ret = gpio_pin_configure(gpio_dev, 14, GPIO_OUTPUT | GPIO_OPEN_DRAIN);
                        if (ret == 0)
                        {
                                ret = gpio_pin_set_raw(gpio_dev, 14, 0);
                                int raw_state = gpio_pin_get_raw(gpio_dev, 14);
                                LOG_INF("Method 3 (raw open-drain) result: set_result=%d, raw_pin_state=%d", ret, raw_state);
                        }
                }
        }

        // Final verification
        int final_pin_state = gpio_pin_get_dt(&vbat_enable);
        LOG_INF("Final P0.14 state: %d (configured as current sink)", final_pin_state);

        if (final_pin_state != 0)
        {
                LOG_WRN("P0.14 not sinking current properly - voltage divider may not work");
        }
        else
        {
                LOG_INF("P0.14 configured as current sink - should enable voltage divider");
        }

        // Initialize controller buttons
        buttons_init();

        // Initialize ADC for analog inputs
        adc_init();

        // Initialize ESB communication
        esb_comm_init();

        // Initialize I2C for trackpad (when connected) - MOVED TO LATER
        i2c_dev = DEVICE_DT_GET(DT_NODELABEL(i2c1));

        // Get I2C0 for IMU
        const struct device *imu_i2c_dev = DEVICE_DT_GET(DT_NODELABEL(i2c0));
        if (!device_is_ready(imu_i2c_dev))
        {
                LOG_ERR("I2C0 device not ready for IMU");
        }
        else
        {
                LOG_INF("I2C0 ready for IMU");
        }

        // Initialize SSD1306 display using display library
        LOG_INF("About to call display_library_init(CONTROLLER_ID=%d)", CONTROLLER_ID);
        ret = display_library_init(CONTROLLER_ID);
        LOG_INF("display_library_init returned: %d, status now: %d", ret, display_get_status());
        if (ret != 0)
        {
                LOG_WRN("Display initialization failed: %d", ret);
        }
        else
        {
                LOG_INF("Display library initialized successfully");
        }

        // Initialize haptic motor driver using haptic_driver library
        // Initialize haptic motor driver using haptic_driver library
        ret = haptic_driver_init(i2c_dev, &haptic_trigger, &haptic_enable_pin);
        if (ret != 0)
        {
                LOG_WRN("Haptic driver initialization failed: %d", ret);
        }
        else
        {
                // Small delay for DRV2605 to fully initialize
                k_sleep(K_MSEC(100));

                // Perform LRA auto-calibration BEFORE setting up external trigger
                LOG_INF("Starting LRA haptic auto-calibration...");
                ret = haptic_perform_lra_calibration();
                if (ret != 0)
                {
                        LOG_WRN("Haptic auto-calibration failed: %d", ret);
                }

                // Setup external trigger mode with LRA-optimized effect (after calibration)
                ret = haptic_setup_external_trigger(DRV2605_EFFECT_SHARP_TICK_2);
                if (ret != 0)
                {
                        LOG_WRN("Haptic external trigger setup failed: %d", ret);
                }
                else
                {
                        // Test haptic motor with a quick pulse to verify it's working
                        k_sleep(K_MSEC(50));
                        gpio_pin_set_dt(&haptic_trigger, 1);
                        k_sleep(K_MSEC(50));
                        gpio_pin_set_dt(&haptic_trigger, 0);
                        LOG_INF("Haptic motor test pulse sent");
                }
        }

        // Initialize power management (with combos disabled for now)
        power_mgmt_config_t power_config = {
            .wake_button1 = &mode_button,         // Use mode button as wake button
            .wake_button2 = NULL,                 // Use existing button as wake button 2
            .status_led = &led0,                  // Use system LED for status
            .shutdown_combo_hold_ms = 5000,       // 30 second hold for shutdown (very long to prevent accidental)
            .factory_reset_combo_hold_ms = 50000, // 50 second hold for factory reset (very long)
            .auto_sleep_enabled = false,          // Disable auto-sleep for now
            .auto_sleep_timeout_ms = 300000       // 5 minutes auto-sleep (when enabled)
        };

        power_mgmt_status_t pm_status = power_mgmt_driver_init(&power_config);
        if (pm_status != POWER_MGMT_STATUS_OK)
        {
                LOG_WRN("Power management initialization failed: %d", pm_status);
        }

        // Register power management callbacks for peripheral control
        power_mgmt_register_shutdown_callback(shutdown_all_peripherals);
        power_mgmt_register_wakeup_callback(wakeup_all_peripherals);

        // Disable button combos to prevent accidental system restart
        // These will only be enabled when intentionally entering sleep mode
        power_mgmt_enable_combo(BUTTON_COMBO_SHUTDOWN, false);
        power_mgmt_enable_combo(BUTTON_COMBO_FACTORY_RESET, false);
        LOG_INF("Power management button combos disabled for normal operation");

        // Initialize storage subsystem
        ret = controller_storage_init();
        if (ret != 0)
        {
                LOG_ERR("Failed to initialize storage: %d", ret);
                // Continue without storage - use defaults
        }
        else
        {
                // Load configuration from flash
                controller_storage_load_calibration(&controller_calibration);
                controller_storage_load_bindings(&controller_bindings);
                controller_storage_load_preferences(&controller_preferences);
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

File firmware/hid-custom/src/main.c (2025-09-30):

#include <stdint.h>
#include <string.h>
#include <zephyr/kernel.h>
#include <zephyr/device.h>
#include <zephyr/drivers/gpio.h>
#include "controller_esb.h"
#include "usb_hid_composite.h"

#include <zephyr/logging/log.h>
LOG_MODULE_REGISTER(main, LOG_LEVEL_INF);

bool left_trackpad_pressed = false;
bool right_trackpad_pressed = false;

bool left_mode_pressed = false;
bool right_mode_pressed = false;

static const struct gpio_dt_spec led0 = GPIO_DT_SPEC_GET(DT_ALIAS(led0), gpios);
// Helper function to map a value from one range to another
long map(long x, long in_min, long in_max, long out_min, long out_max)
{
    return (x - in_min) * (out_max - out_min) / (in_max - in_min) + out_min;
}

// Convert controller data to HID reports (using separated controller states)
static void process_controller_data(const struct device *hid_dev)
{
    uint32_t func_start = k_uptime_get_32();
    
    // Get SEPARATE controller states - no more shared state corruption!
    simple_controller_state_t *left_controller = controller_esb_get_left_state();
    simple_controller_state_t *right_controller = controller_esb_get_right_state();

    // Static variables to hold complete state
    static uint8_t dpad = 8;
    static uint8_t buttons1 = 0, buttons2 = 0;
    static uint8_t left_x = 128, left_y = 128;
    static uint8_t right_x = 128, right_y = 128;
    static uint8_t left_trigger = 0, right_trigger = 0;
    static bool touch1_active = false;
    static bool touch2_active = false;
    static uint16_t touch1_x = 0, touch1_y = 0;
    static uint16_t touch2_x = 0, touch2_y = 0;
    static int16_t accel_x = 0, accel_y = 0, accel_z = 0;
    static int16_t gyro_x = 0, gyro_y = 0, gyro_z = 0;

    static uint16_t raw_touch2_x = 0;
    static uint16_t raw_touch2_y = 0;

    static uint16_t last_touch2_x = 0, last_touch2_y = 0;
    static bool last_touch2_active = false;
    static float interp_factor = 0.7f; // Adjust for smoothness

    static uint16_t raw_touch_x = 0;
    static uint16_t raw_touch_y = 0;

    // Static variables for interpolation
    static uint16_t last_touch_x = 0, last_touch_y = 0;
    static bool last_touch_active = false;

    // Process LEFT controller data independently
    if (left_controller->data_received)
    {
        // Left controller data
        left_x = (uint8_t)(left_controller->stickX + 128);
        left_y = (uint8_t)(left_controller->stickY + 128);
        left_trigger = left_controller->trigger;

        // Touchpad from left controller
        touch2_active = (left_controller->padX != 0 || left_controller->padY != 0);

        // Raw trackpad values after mapping
        raw_touch2_x = touch2_active ? (map(left_controller->padY, 0, 1023, 959, 0)) : 0;
        raw_touch2_y = touch2_active ? (map(left_controller->padX, 0, 1023, 0, 942)) : 0;

        // Left controller Dpad processing
        if ((left_controller->buttons & 0x08) && !(left_controller->buttons & 0x04) && !(left_controller->buttons & 0x02) && !(left_controller->buttons & 0x01)) // just down
        {
            dpad = 4; // Down
        }
        if (!(left_controller->buttons & 0x08) && (left_controller->buttons & 0x04) && !(left_controller->buttons & 0x02) && !(left_controller->buttons & 0x01)) // just right
        {
            dpad = 2; // Right
        }
        if (!(left_controller->buttons & 0x08) && !(left_controller->buttons & 0x04) && (left_controller->buttons & 0x02) && !(left_controller->buttons & 0x01)) // just left
        {
            dpad = 6; // Left
        }
        if (!(left_controller->buttons & 0x08) && !(left_controller->buttons & 0x04) && !(left_controller->buttons & 0x02) && (left_controller->buttons & 0x01)) // just up
        {
            dpad = 0; // Up
        }
        if ((left_controller->buttons & 0x08) && (left_controller->buttons & 0x04) && !(left_controller->buttons & 0x02) && !(left_controller->buttons & 0x01)) // down right
        {
            dpad = 3; // Down Right
        }
        if (!(left_controller->buttons & 0x08) && (left_controller->buttons & 0x04) && !(left_controller->buttons & 0x02) && (left_controller->buttons & 0x01)) // right up
        {
            dpad = 1; // Right Up
        }
        if ((left_controller->buttons & 0x08) && !(left_controller->buttons & 0x04) && (left_controller->buttons & 0x02) && !(left_controller->buttons & 0x01)) // down left
        {
            dpad = 5; // Left Down
        }
        if (!(left_controller->buttons & 0x08) && !(left_controller->buttons & 0x04) && (left_controller->buttons & 0x02) && (left_controller->buttons & 0x01)) // left up
        {
            dpad = 7; // Up Left
        }
        if (!(left_controller->buttons & 0x08) && !(left_controller->buttons & 0x04) && !(left_controller->buttons & 0x02) && !(left_controller->buttons & 0x01)) // neutral
        {
            dpad = 8; // neutral
        }

        // Left controller buttons
        if (left_controller->buttons & 0x10 || left_controller->flags & 0x01) // 0x01 is P5 just hard coding it for now
        {
            buttons1 |= (1 << 4); // Bumper
        }
        else
        {
            buttons1 &= ~(1 << 4); // Bumper
        }

        if (left_controller->buttons & 0x40)
        {
            buttons2 |= (1 << 5); // Trackpad Click
            left_trackpad_pressed = true;
        }
        else
        {
            left_trackpad_pressed = false;
        }

        if (left_controller->buttons & 0x20 || left_controller->flags & 0x02) // 0x02 is P4 just hard coding it for now
        {
            buttons2 |= (1 << 2); // Stick Click
        }
        else
        {
            buttons2 &= ~(1 << 2); // Stick Click
        }

        if (left_controller->buttons & 0x80)
        {
            buttons2 |= (1 << 0); // Select
        }
        else
        {
            buttons2 &= ~(1 << 0); // Select
        }

        if (left_controller->flags & 0x40)
        {
            buttons2 |= (1 << 4); // PS button
            left_mode_pressed = true;
        }
        else
        {
            left_mode_pressed = false;
        }
    }

    // Process RIGHT controller data independently
    if (right_controller->data_received)
    {
        // Right controller data
        right_x = (uint8_t)(right_controller->stickX + 128);
        right_y = (uint8_t)(right_controller->stickY + 128);
        right_trigger = right_controller->trigger;

        // IMU from right controller only
        accel_x = right_controller->accelX;
        accel_y = right_controller->accelY;
        accel_z = right_controller->accelZ;
        gyro_x = right_controller->gyroX;
        gyro_y = right_controller->gyroY;
        gyro_z = right_controller->gyroZ;

        gyro_y = -gyro_y;
        accel_y = -accel_y;
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

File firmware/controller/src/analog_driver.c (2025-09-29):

/**
 ******************************************************************************
 * @file    analog_driver.c
 * @brief   ADC Analog Input Driver Library Implementation
 * @author  Controller Team
 * @version V1.0
 * @date    2025
 ******************************************************************************
 */

#include "analog_driver.h"
#include <zephyr/logging/log.h>
#include <zephyr/drivers/gpio.h>
#include <hal/nrf_saadc.h>
#include <math.h>
#include <stdlib.h>

LOG_MODULE_REGISTER(analog_driver, LOG_LEVEL_INF);

// Global context
static analog_driver_context_t g_analog_ctx = {0};

// Battery voltage divider enable pin (P0.14)
static const struct gpio_dt_spec battery_enable_pin = {
    .port = DEVICE_DT_GET(DT_NODELABEL(gpio0)),
    .pin = 14,
    .dt_flags = GPIO_OUTPUT_ACTIVE
};

// Default configuration
static const analog_config_t default_config = {
    .resolution_bits = 12,
    .gain = ADC_GAIN_1_6,
    .reference = ADC_REF_INTERNAL,
    .acquisition_time = ADC_ACQ_TIME(ADC_ACQ_TIME_MICROSECONDS, 40), // Increased for rapidly changing signals
    .filter_alpha = 0.8f // Lighter filtering for better responsiveness
};

// Channel names for debugging
static const char *channel_names[ANALOG_CHANNEL_COUNT] = {
    "STICK_X",
    "STICK_Y", 
    "TRIGGER",
    "BATTERY"
};

/**
 * @brief Initialize the analog driver
 */
analog_status_t analog_driver_init(const struct device *adc_device)
{
    LOG_INF("Initializing analog driver...");

    if (!adc_device || !device_is_ready(adc_device))
    {
        LOG_ERR("ADC device not ready");
        return ANALOG_STATUS_ERROR;
    }

    // Clear context
    memset(&g_analog_ctx, 0, sizeof(g_analog_ctx));

    // Store ADC device and configuration
    g_analog_ctx.adc_dev = adc_device;
    g_analog_ctx.config = default_config;

    // Initialize battery enable pin (P0.14)
    if (!gpio_is_ready_dt(&battery_enable_pin))
    {
        LOG_ERR("Battery enable pin not ready");
        return ANALOG_STATUS_ERROR;
    }
    
    int ret = gpio_pin_configure_dt(&battery_enable_pin, GPIO_OUTPUT_INACTIVE);
    if (ret < 0)
    {
        LOG_ERR("Failed to configure battery enable pin: %d", ret);
        return ANALOG_STATUS_ERROR;
    }
    
    // Enable battery voltage divider
    gpio_pin_set_dt(&battery_enable_pin, 0); // Active low - enable divider
    LOG_INF("Battery voltage divider enabled");

    // Configure channel mappings (for nRF52840 SAADC)
    g_analog_ctx.channel_configs[ANALOG_CHANNEL_STICK_X] = (analog_channel_config_t){
        .adc_channel = 0,
        .adc_input = NRF_SAADC_INPUT_AIN0, // P0.02
        .name = "StickX"};

    g_analog_ctx.channel_configs[ANALOG_CHANNEL_STICK_Y] = (analog_channel_config_t){
        .adc_channel = 1,
        .adc_input = NRF_SAADC_INPUT_AIN1, // P0.03
        .name = "StickY"};

    g_analog_ctx.channel_configs[ANALOG_CHANNEL_TRIGGER] = (analog_channel_config_t){
        .adc_channel = 2,
        .adc_input = NRF_SAADC_INPUT_AIN4, // P0.28
        .name = "Trigger"};

    g_analog_ctx.channel_configs[ANALOG_CHANNEL_BATTERY] = (analog_channel_config_t){
        .adc_channel = 3,
        .adc_input = NRF_SAADC_INPUT_AIN7, // P0.31 - Battery via voltage divider
        .name = "Battery"};

    // Configure ADC channels
    for (int i = 0; i < ANALOG_CHANNEL_COUNT; i++)
    {
        struct adc_channel_cfg *cfg = &g_analog_ctx.adc_channel_configs[i];
        const analog_channel_config_t *ch_cfg = &g_analog_ctx.channel_configs[i];

        cfg->gain = g_analog_ctx.config.gain;
        cfg->reference = g_analog_ctx.config.reference;
        cfg->acquisition_time = g_analog_ctx.config.acquisition_time;
        cfg->channel_id = ch_cfg->adc_channel;
        cfg->differential = 0;
        cfg->input_positive = ch_cfg->adc_input;
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

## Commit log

2025-09-29 First Big Release
    Probably going to do this in pieces and then also go through one by one to update the readmes
    [Fake PCB LCD Trackpad Left.stl, Fake PCB LCD Trackpad Right.stl, Fake PCB Oled Trackpad Left.stl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]
2025-09-29 Adding the Cad Files
    Adding the cad files but the experimental stuff for anyone who wanted to mess with it
    [Bottom Dongle Case 2.stl, Bottom Dongle Case.stl, Left Controller v3 Bottom.stl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]
2025-09-30 Changing button processing logic
    Fixes Rare case of data being modified mid processing making left and right data get confused
    [controller_esb.c, main.c]
2025-10-02 Update README with link to BOM
